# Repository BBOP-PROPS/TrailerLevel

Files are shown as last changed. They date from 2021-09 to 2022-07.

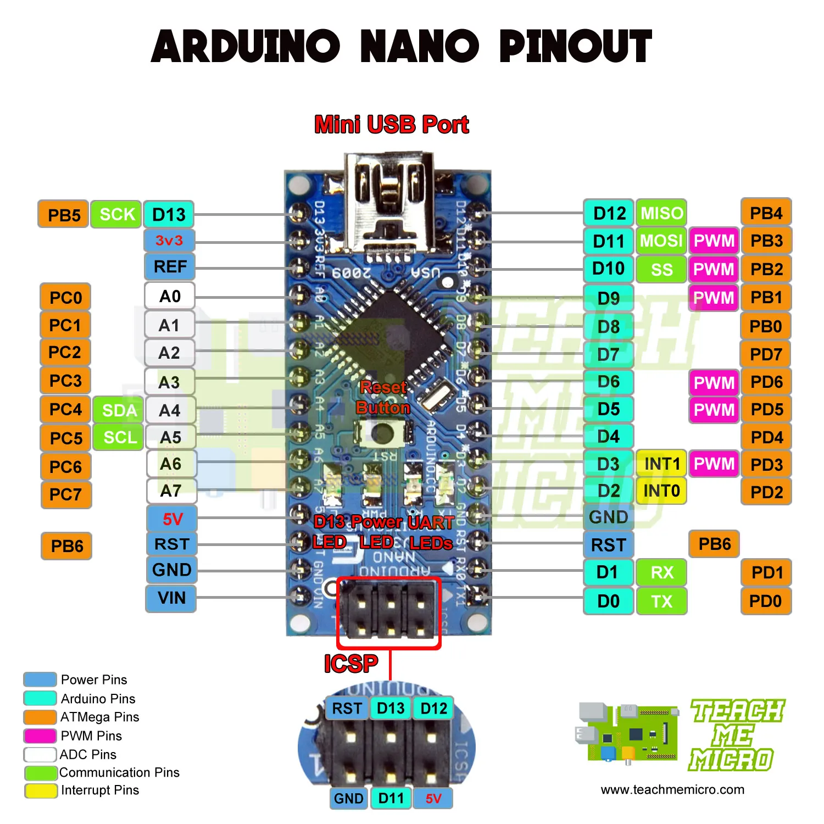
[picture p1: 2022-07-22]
doc/Arduino-Nano-pinout.png

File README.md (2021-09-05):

# TrailerLevel
Wireless level for semi-trailer

This project consists of a sender and receiver originally developed using an Arduino Nano for each side.
The sender utilizes a GY521 sensor with a three-axis accelerometer and three-axis gyroscope.
The receiver contains a 20x4 LCD display with an I2C interface.
The sender and receiver communicate with a cheap 433 MHz radio.

# Dependencies
To build these projects you will need to install the following Arduino libraries:

* RadioHead
* GY521
* LiquidCrystal I2C

# Boxes
The 3D models for the boxes and lids were created in OpenSCAD.
It is recommended to use PETG or ABS for durabiity. PLA is not recommended.

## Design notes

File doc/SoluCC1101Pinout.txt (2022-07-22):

This pinout is for the CC1101 module on a blue board with black 8-pin connector and short spring antenna.

1.GND  2.VCC

3.GDO0 4.CSN

5.SCLK 6.MOSI

7.MISO 8.GDO2

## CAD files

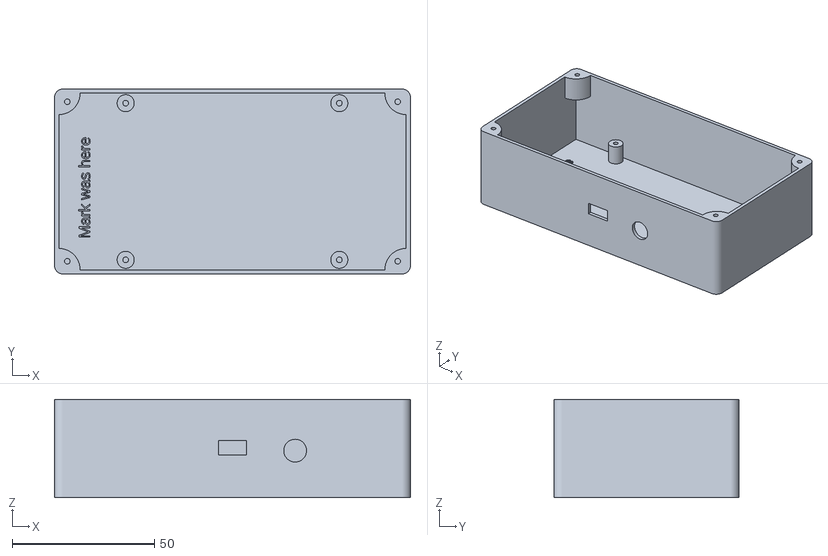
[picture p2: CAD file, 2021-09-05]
LevelReceiver/Box/ReceiverBox.stl
125.0 x 65.0 x 34.5

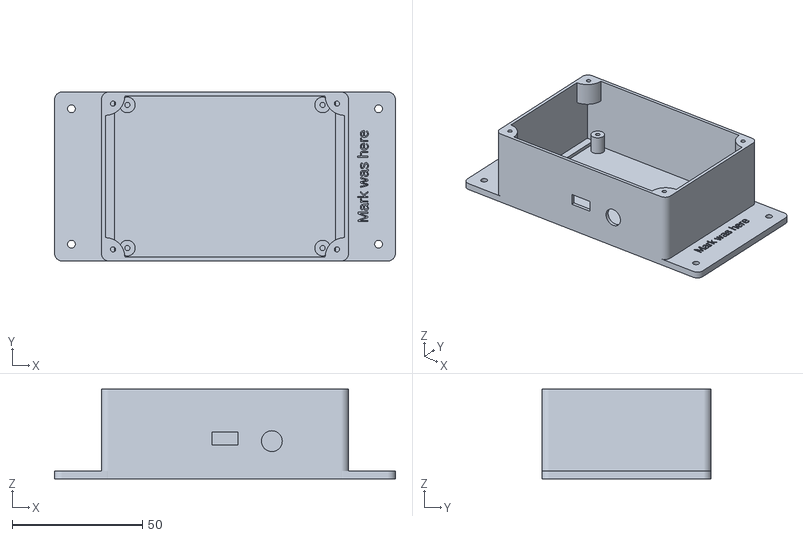
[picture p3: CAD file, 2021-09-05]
LevelSender/Box/TransmitterBoxBottom.stl
131.0 x 65.0 x 34.5

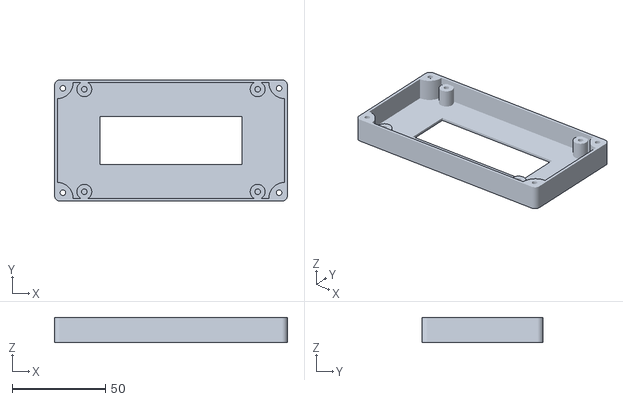
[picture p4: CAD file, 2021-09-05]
LevelReceiver/Box/ReceiverBoxLid.stl
125.0 x 65.0 x 13.5

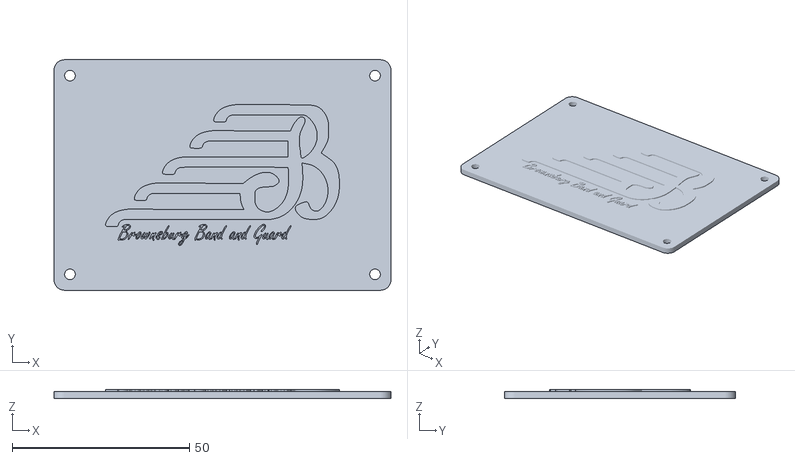
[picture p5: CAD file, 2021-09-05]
LevelSender/Box/TransmitterBoxLid.stl
95.0 x 65.0 x 2.50

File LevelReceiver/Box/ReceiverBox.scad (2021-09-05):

$fn=100;


shell = 1.5;
pcbWidth = 80;
pcbLength = 60;
clearance = 2;
boxWidth = 120;
lcdWidth = 98;
lcdLength = 60;

//Box(boxWidth + clearance, 60 + clearance, 33);
//Screws(2, 6, 8, 80, 60, 2.5);
//translate([0, 0, 33 + shell - 10]) LidScrews(2, 15, 10, boxWidth + clearance, 60 + clearance, 3);
//translate([-50, -20, shell]) linear_extrude(height=0.5) rotate([0,0,90]) text(size = 4, "Mark was here");

difference()
{
  union()
  {
    difference()
    {
      Box(boxWidth + clearance, 60 + clearance, 12);
      cube([76, 26, 5], center = true);
      translate([0,0,-0.5]) LidScrewHoles(3, 12+shell, boxWidth + clearance, 60 + clearance, 3);
    }
    Screws(3, 8, 9.5, lcdWidth, lcdLength, 2.5);
    LidScrews(3, 17, 12+shell, boxWidth + clearance, 60 + clearance, 3);
  }
  LidScrewHoles(7, 5, boxWidth + clearance, 60 + clearance, 3);
}
module Box(width, length, height)
{
  difference()
  {
    hull()
    {
      translate([-width/2+shell, -length/2+shell, 0]) cylinder(r=shell*2,h=height + shell);
      translate([+width/2-shell, -length/2+shell, 0]) cylinder(r=shell*2,h=height + shell);
      translate([+width/2-shell, +length/2-shell, 0]) cylinder(r=shell*2,h=height + shell);
      translate([-width/2+shell, +length/2-shell, 0]) cylinder(r=shell*2,h=height + shell);
    }
    translate([-width/2, -length/2, shell]) cube([width, length, height + 1]);
//    translate([22, -length/2+0.5, 7+8+shell]) rotate([90, 0, 0]) cylinder(d=8, h=shell+1);
//    translate([0, -length/2-0.5, 8+8+shell]) cube([10, shell+1, 5], center=true);
  }
}

module Screw(inside, outside, height)
{
  difference()
  {
    cylinder(d = outside, h = height);
    cylinder(d = inside, h = height + 1);
  }
}

module Screws(inside, outside, height, width, length, inset)
{
  translate([-width/2 + inset, -length/2 + inset, shell]) Screw(inside, outside, height);
  translate([+width/2 - inset, -length/2 + inset, shell]) Screw(inside, outside, height);
  translate([+width/2 - inset, +length/2 - inset, shell]) Screw(inside, outside, height);
  translate([-width/2 + inset, +length/2 - inset, shell]) Screw(inside, outside, height);
}

module LidScrew(inside, outside, height, inset)
{
  difference()
  {
    cylinder(d = outside, h = height);
    translate([inset, inset, -0.5]) cylinder(d = inside, h = height + 1);
    translate([-outside/2, -outside-1, 0]) cube([outside + 1, outside + 1, height + 1]);
    translate([-outside-1, -outside/2, 0]) cube([outside + 1, outside + 1, height + 1]);
  }
}

module LidScrews(inside, outside, height, width, length, inset)
{
  translate([-width/2, -length/2, 0]) LidScrew(inside, outside, height, inset);
  translate([+width/2, -length/2, 0]) rotate([0, 0, 90]) LidScrew(inside, outside, height, inset);
  translate([+width/2, +length/2, 0]) rotate([0, 0, 180]) LidScrew(inside, outside, height, inset);
  translate([-width/2, +length/2, 0]) rotate([0, 0, 270]) LidScrew(inside, outside, height, inset);
}


module LidScrewHole(inside, height, inset)
{
  translate([inset, inset, 0]) cylinder(d = inside, h = height + 1);
}

module LidScrewHoles(inside, height, width, length, inset)
{
  translate([-width/2, -length/2, 0]) LidScrewHole(inside, height, inset);
  translate([+width/2, -length/2, 0]) rotate([0, 0, 90]) LidScrewHole(inside, height, inset);
  translate([+width/2, +length/2, 0]) rotate([0, 0, 180]) LidScrewHole(inside, height, inset);
  translate([-width/2, +length/2, 0]) rotate([0, 0, 270]) LidScrewHole(inside, height, inset);
}

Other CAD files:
LevelSender/Box/TransmitterBoxBottom.scad

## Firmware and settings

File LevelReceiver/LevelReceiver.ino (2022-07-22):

//
//    FILE: LevelReceiver.ino
//  AUTHOR: Mark Nierzwick
// VERSION: 0.0.0
// PURPOSE: minimal demo
//    DATE: 2021-03-28

//#define SERIAL_OUTPUT // used for debugging

#include <Wire.h>
#include <LiquidCrystal_I2C.h>
#include <Math.h>

#if defined(ARDUINO) && ARDUINO >= 100
#define printByte(args)  write(args);
#else
#define printByte(args)  print(args,BYTE);
#endif

#include <Arduino.h>
#include <cc1101.h>
#include <ccpacket.h>
// Attach CC1101 pins to their corresponding SPI pins
// Uno pins:
// CSN (SS) => 10
// MOSI => 11
// MISO => 12
// SCK => 13
// GD0 => A valid interrupt pin for your platform (defined below this)
#if defined(__AVR_ATmega2560__) || defined(__AVR_ATmega1280__)
#define CC1101Interrupt 4 // Pin 19
#define CC1101_GDO0 19
#elif defined(__MK64FX512__)
// Teensy 3.5
#define CC1101Interrupt 9 // Pin 9
#define CC1101_GDO0 9
#else
#define CC1101Interrupt 0 // Pin 2
#define CC1101_GDO0 2
#endif
#define CC1101_DEFVAL_MDMCFG4_1200    0xC5   // Modem configuration. Speed = 1200 bps

CC1101 radio;
byte syncWord[2] = {199, 10};
bool packetWaiting;
void messageReceived() {
  packetWaiting = true;
}

struct LevelData_t
{
  float angleX = 0.0f;
  float angleY = 0.0f;
  float angleZ = 0.0f;
  float temperature = 0.0f;
};

LiquidCrystal_I2C lcd(0x27, 20, 4); // set the LCD address to 0x27 for a 20 chars and 4 line display

void SplashScreen()
{
  uint8_t logo1[8] = {0x00, 0x00, 0x03, 0x06, 0x00, 0x0F, 0x18, 0x00};
  uint8_t logo2[8] = {0x00, 0x00, 0x1F, 0x00, 0x00, 0x1F, 0x01, 0x01};
  uint8_t logo3[8] = {0x00, 0x00, 0x1C, 0x06, 0x12, 0x02, 0x02, 0x04};
  uint8_t logo4[8] = {0x00, 0x00, 0x00, 0x01, 0x03, 0x00, 0x0F, 0x18};
  uint8_t logo5[8] = {0x07, 0x0C, 0x00, 0x1F, 0x00, 0x00, 0x1F, 0x00};
  uint8_t logo6[8] = {0x1F, 0x00, 0x00, 0x1F, 0x00, 0x00, 0x1F, 0x00};
  uint8_t logo7[8] = {0x1F, 0x01, 0x0D, 0x11, 0x11, 0x0A, 0x04, 0x00};
  uint8_t logo8[8] = {0x18, 0x06, 0x01, 0x01, 0x01, 0x16, 0x18, 0x00};
  lcd.createChar(0, logo1);
  lcd.createChar(1, logo2);
  lcd.createChar(2, logo3);
  lcd.createChar(3, logo4);
  lcd.createChar(4, logo5);
  lcd.createChar(5, logo6);
  lcd.createChar(6, logo7);
  lcd.createChar(7, logo8);
  lcd.clear();
  lcd.home();
  lcd.setCursor(2, 0);
  lcd.print("Brownsburg Bands");
  lcd.setCursor(9, 1);
  for (int i = 0; i < 3; i++)
    lcd.printByte(i);
  lcd.setCursor(7, 2);
  for (int i = 3; i < 8; i++)
    lcd.printByte(i);
  lcd.setCursor(0, 3);
  lcd.print("Level Utility     MN");
}

void setup()
{
#ifdef SERIAL_OUTPUT
  Serial.begin(115200);
  Serial.println(__FILE__);
#endif
  radio.init();
  radio.setSyncWord(syncWord);
  radio.setCarrierFreq(CFREQ_433);
  radio.disableAddressCheck();
  radio.setTxPowerAmp(PA_LongDistance);
  radio.writeReg(CC1101_MDMCFG4, CC1101_DEFVAL_MDMCFG4_1200); // Set the bit rate to 1200 for better receiver sensitivity
  attachInterrupt(CC1101Interrupt, messageReceived, FALLING);

  lcd.init();                      // initialize the lcd
  lcd.backlight();
  SplashScreen();
  delay(5000);
}

void displayFloat(uint8_t row, uint8_t col, float x)
{
  char xstr[6];
  dtostrf(x, 3, 1, xstr);
  lcd.setCursor(row, col);
  lcd.print("     ");
  lcd.setCursor(row, col);
  lcd.print(xstr);
}

// Get signal strength indicator in dBm.
// See: http://www.ti.com/lit/an/swra114d/swra114d.pdf
int rssi(char raw) {
  uint8_t rssi_dec;
  // TODO: This rssi_offset is dependent on baud and MHz; this is for 38.4kbps and 433 MHz.
  uint8_t rssi_offset = 74;
  rssi_dec = (uint8_t) raw;
  if (rssi_dec >= 128)
    return ((int)( rssi_dec - 256) / 2) - rssi_offset;
  else
    return (rssi_dec / 2) - rssi_offset;
}

// Get link quality indicator.
int lqi(char raw) {
  return 0x3F - raw;
}

void loop()
{
  static bool noSignal = false;
  LevelData_t dataReceived;
  static unsigned long lastReceivedTime = 0;
  uint8_t buflen = sizeof(dataReceived);

  if (packetWaiting)
  {
    detachInterrupt(CC1101Interrupt);
    packetWaiting = false;
    CCPACKET packet;
    if (radio.receiveData(&packet) > 0)
    {
      if (packet.crc_ok)
      {
        memcpy((char*)&dataReceived, (char*)&packet.data, max(packet.length, sizeof(dataReceived)));
        lastReceivedTime = millis();
        lcd.setCursor(0, 2);
        lcd.print("Angle");
        if (noSignal)
        {
          noSignal = false;
          lcd.setCursor(0, 3);
          lcd.print("                    ");
        }
        displayFloat(0, 3, dataReceived.angleX);
#ifdef SERIAL_OUTPUT
        Serial.println(dataReceived.angleX);
#endif
        float angleRadians = dataReceived.angleX * 2.0 * PI / 360.0;
        float adjustment = 102 * sin(angleRadians);
        lcd.setCursor(15, 2);
        if (adjustment > 0)
          lcd.print("Left ");
        else
          lcd.print("Right");
        displayFloat(15, 3, fabsf(adjustment));
      }
#ifdef SERIAL_OUTPUT
      Serial.println(F("Received packet..."));
      if (!packet.crc_ok)
      {
        Serial.println(F("crc not ok"));
      }
      Serial.print(F("lqi: "));
      Serial.println(lqi(packet.lqi));
      Serial.print(F("rssi: "));
      Serial.print(rssi(packet.rssi));
      Serial.println(F("dBm"));

      if (packet.crc_ok && packet.length > 0)
      {
        Serial.print(F("packet: len "));
        Serial.println(packet.length);
        Serial.println(F("data: "));
        Serial.println((const char *) packet.data);
      }
#endif
    }
    attachInterrupt(CC1101Interrupt, messageReceived, FALLING);
  }
  else
  {
    if (((millis() - lastReceivedTime) > 3000) && !noSignal)
    {
#ifdef SERIAL_OUTPUT
      Serial.println((millis() - lastReceivedTime));
#endif
      lcd.setCursor(0, 3);
      lcd.print("No Signal           ");
      noSignal = true;
    }
  }
}

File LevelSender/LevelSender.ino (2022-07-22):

//
//    FILE: LevelSender.ino
//  AUTHOR: Mark Nierzwick
// VERSION: 0.0.0
// PURPOSE: minimal demo
//    DATE: 2021-03-28

//#define SERIAL_OUTPUT // used for debugging

#include "GY521.h" // 3-axis accelerometer and gyro

#include <Arduino.h>
#include <cc1101.h>
#include <ccpacket.h>
// Attach CC1101 pins to their corresponding SPI pins
// Uno pins:
// CSN (SS) => 10
// MOSI => 11
// MISO => 12
// SCK => 13
// GD0 => A valid interrupt pin for your platform (defined below this)
#if defined(__AVR_ATmega2560__) || defined(__AVR_ATmega1280__)
#define CC1101Interrupt 4 // Pin 19
#define CC1101_GDO0 19
#elif defined(__MK64FX512__)
// Teensy 3.5
#define CC1101Interrupt 9 // Pin 9
#define CC1101_GDO0 9
#else
#define CC1101Interrupt 0 // Pin 2
#define CC1101_GDO0 2
#endif
#define CC1101_DEFVAL_MDMCFG4_1200    0xC5   // Modem configuration. Speed = 1200 bps

CC1101 radio;
byte syncWord[2] = {199, 10};
bool packetWaiting;
void messageReceived() {
    packetWaiting = true;
}

GY521 sensor(0x68);

uint32_t counter = 0;

struct LevelData_t
{
  float angleX = 0.0f;
  float angleY = 0.0f;
  float angleZ = 0.0f;
  float temperature = 0.0f;
};
LevelData_t dataToSend;

void setup()
{
#ifdef SERIAL_OUTPUT
  Serial.begin(115200);
  Serial.println(__FILE__);
#endif
  radio.init();
  radio.setSyncWord(syncWord);
  radio.setCarrierFreq(CFREQ_433);
  radio.disableAddressCheck();
  radio.setTxPowerAmp(PA_LongDistance);
  radio.writeReg(CC1101_MDMCFG4, CC1101_DEFVAL_MDMCFG4_1200); // Set the bit rate to 1200 for better receiver sensitivity
  attachInterrupt(CC1101Interrupt, messageReceived, FALLING);
  
  Wire.begin();
  while (sensor.wakeup() == false)
  {
#ifdef SERIAL_OUTPUT
    Serial.println("\tCould not connect to GY521");
#endif
    delay(1000);
  }

  sensor.setAccelSensitivity(0);  // 2g
  sensor.setGyroSensitivity(0);   // 250 degrees/s
  sensor.setThrottle();
#ifdef SERIAL_OUTPUT
  Serial.println("start...");
#endif
  
  // set callibration values from calibration sketch.
  sensor.axe = 0;
  sensor.aye = 0;
  sensor.aze = 0;
  sensor.gxe = 0;
  sensor.gye = 0;
  sensor.gze = 0;
}

void loop()
{
  if (sensor.read() == GY521_OK)
  {
    // For some reason the GY521 sends invalid numbers the first time
    if (!isnan(sensor.getAngleX()))
    {
      // Use an IIR filter for the accelerometer values
      dataToSend.angleX = 0.3 * sensor.getAngleX() + 0.7 * dataToSend.angleX;
      dataToSend.angleY = 0.3 * sensor.getAngleY() + 0.7 * dataToSend.angleY;
      dataToSend.angleZ = 0.3 * sensor.getAngleZ() + 0.7 * dataToSend.angleZ;
      dataToSend.temperature = sensor.getTemperature();
    }
  }

#ifdef SERIAL_OUTPUT
  if (counter % 10 == 0)
  {
    Serial.println("\tangleX\tangleY\tangleZ\ttemperature");
  }

  Serial.print(counter);
  Serial.print('\t');
  Serial.print(dataToSend.angleX);
  Serial.print('\t');
  Serial.print(dataToSend.angleY);
  Serial.print('\t');
  Serial.print(dataToSend.angleZ);
  Serial.print('\t');
  Serial.print(dataToSend.temperature);
  Serial.println();
#endif

  if (counter % 5 == 0)
  {
    detachInterrupt(CC1101Interrupt);
    CCPACKET packet;
    // We also need to include the 0 byte at the end of the string
    packet.length = sizeof(dataToSend);
    memcpy((char *)packet.data, (char *)&dataToSend, packet.length);
    radio.sendData(packet);
    attachInterrupt(CC1101Interrupt, messageReceived, FALLING);
  }
  counter++;
  delay(100);
}

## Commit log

2021-09-05 First implementation
    [ReceiverBox.scad, ReceiverBox.stl, ReceiverBoxLid.stl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]
2022-06-05 Disable serial printing
